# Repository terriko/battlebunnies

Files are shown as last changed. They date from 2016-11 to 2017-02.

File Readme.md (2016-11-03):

# Battle bunnies!

This is a goofy little side project that involves making a little electronic
bunny game in the name of learning a bit more about electronic badge design.

## How the game is played

Battle bunnies is meant to be a simple electronic game.  Each participant
gets their own bunny.  The bunnies have IR on one side of the PCB.
Participants line up their IR with the IR of another bunny and both hit the
"fight" button.  The bunnies each "roll" a random number 1-6 which is shown
on one ear and transmit that number to the other bunny.  The bunny with the
highest number gains a level.  In the case of a tie, both bunnies gain a
level (because why not?).  The levels are updated on the other ear.
Depending on how slow we want the level process to be, losing bunnies might
lose a level.

The "magic" button is an easter egg that can be activated when bunnies reach
max level.

## Bunny design

These are all early drafts which I'm sure we'll change.

### PCB outline
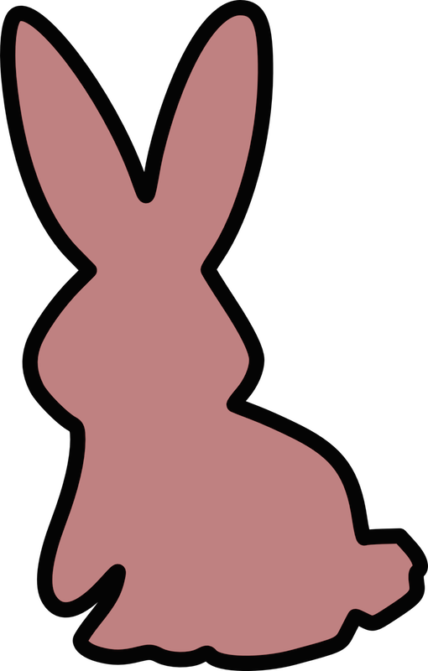
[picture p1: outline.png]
Battle Bunny PCB Outline


### Silkscreen bunny
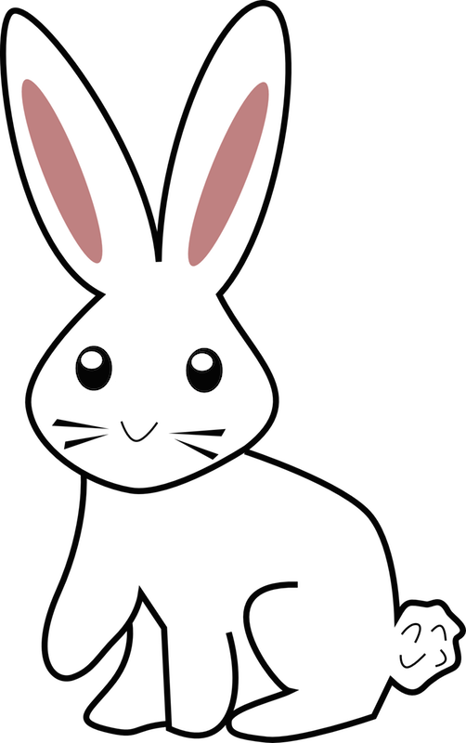
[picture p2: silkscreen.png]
Battle Bunny Silkscreen


### Explanation of what components go where
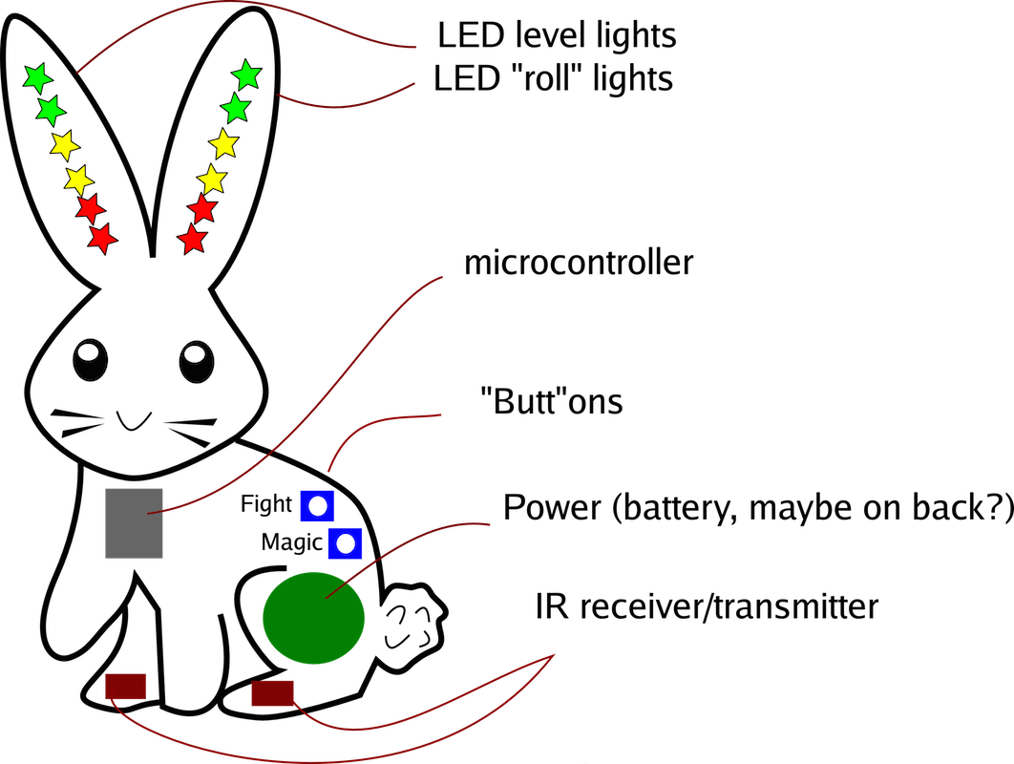
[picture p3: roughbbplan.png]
Battle Bunny details


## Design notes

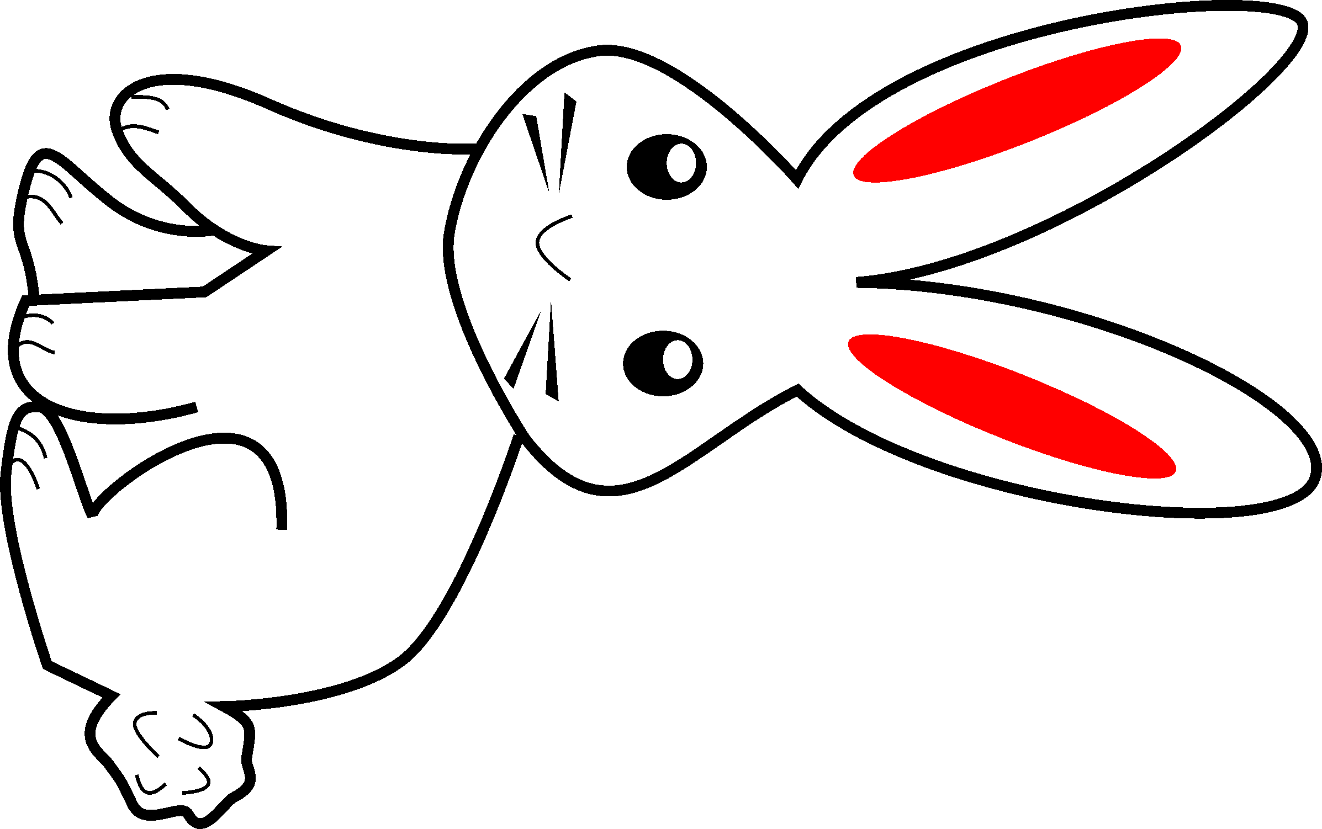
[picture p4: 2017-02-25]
battle bunnies silk.bmp

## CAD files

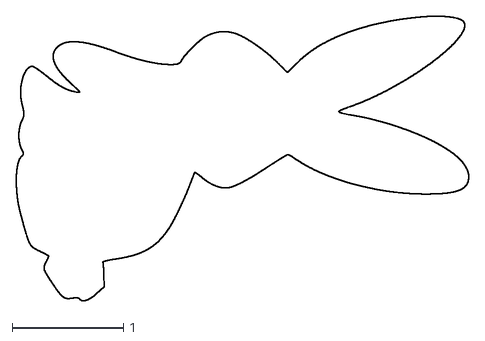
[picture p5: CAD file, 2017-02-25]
battlebunnies outline r9.dxf
4.07 x 2.56

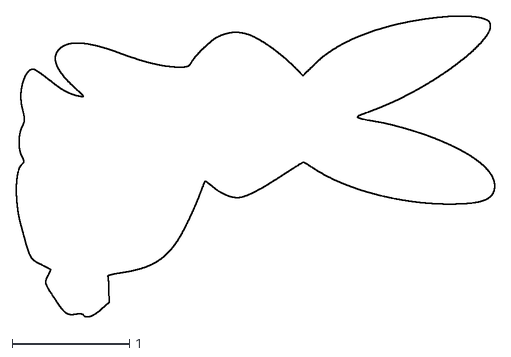
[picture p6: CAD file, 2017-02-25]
battlebunnies outline r12.dxf
4.07 x 2.56

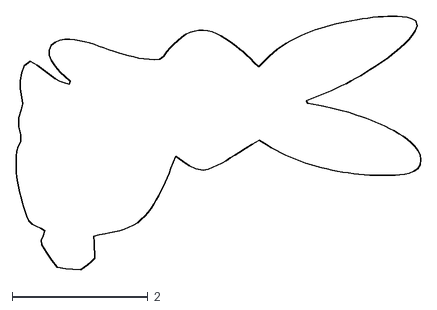
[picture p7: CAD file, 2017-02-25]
battlebunnies outline.dxf
5.97 x 3.74

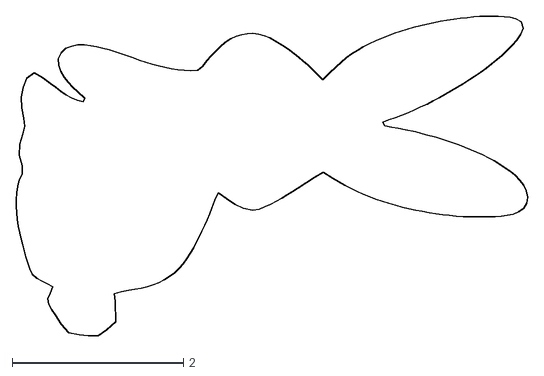
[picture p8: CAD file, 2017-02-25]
battlebunnies outline r12 v2.dxf
5.97 x 3.74

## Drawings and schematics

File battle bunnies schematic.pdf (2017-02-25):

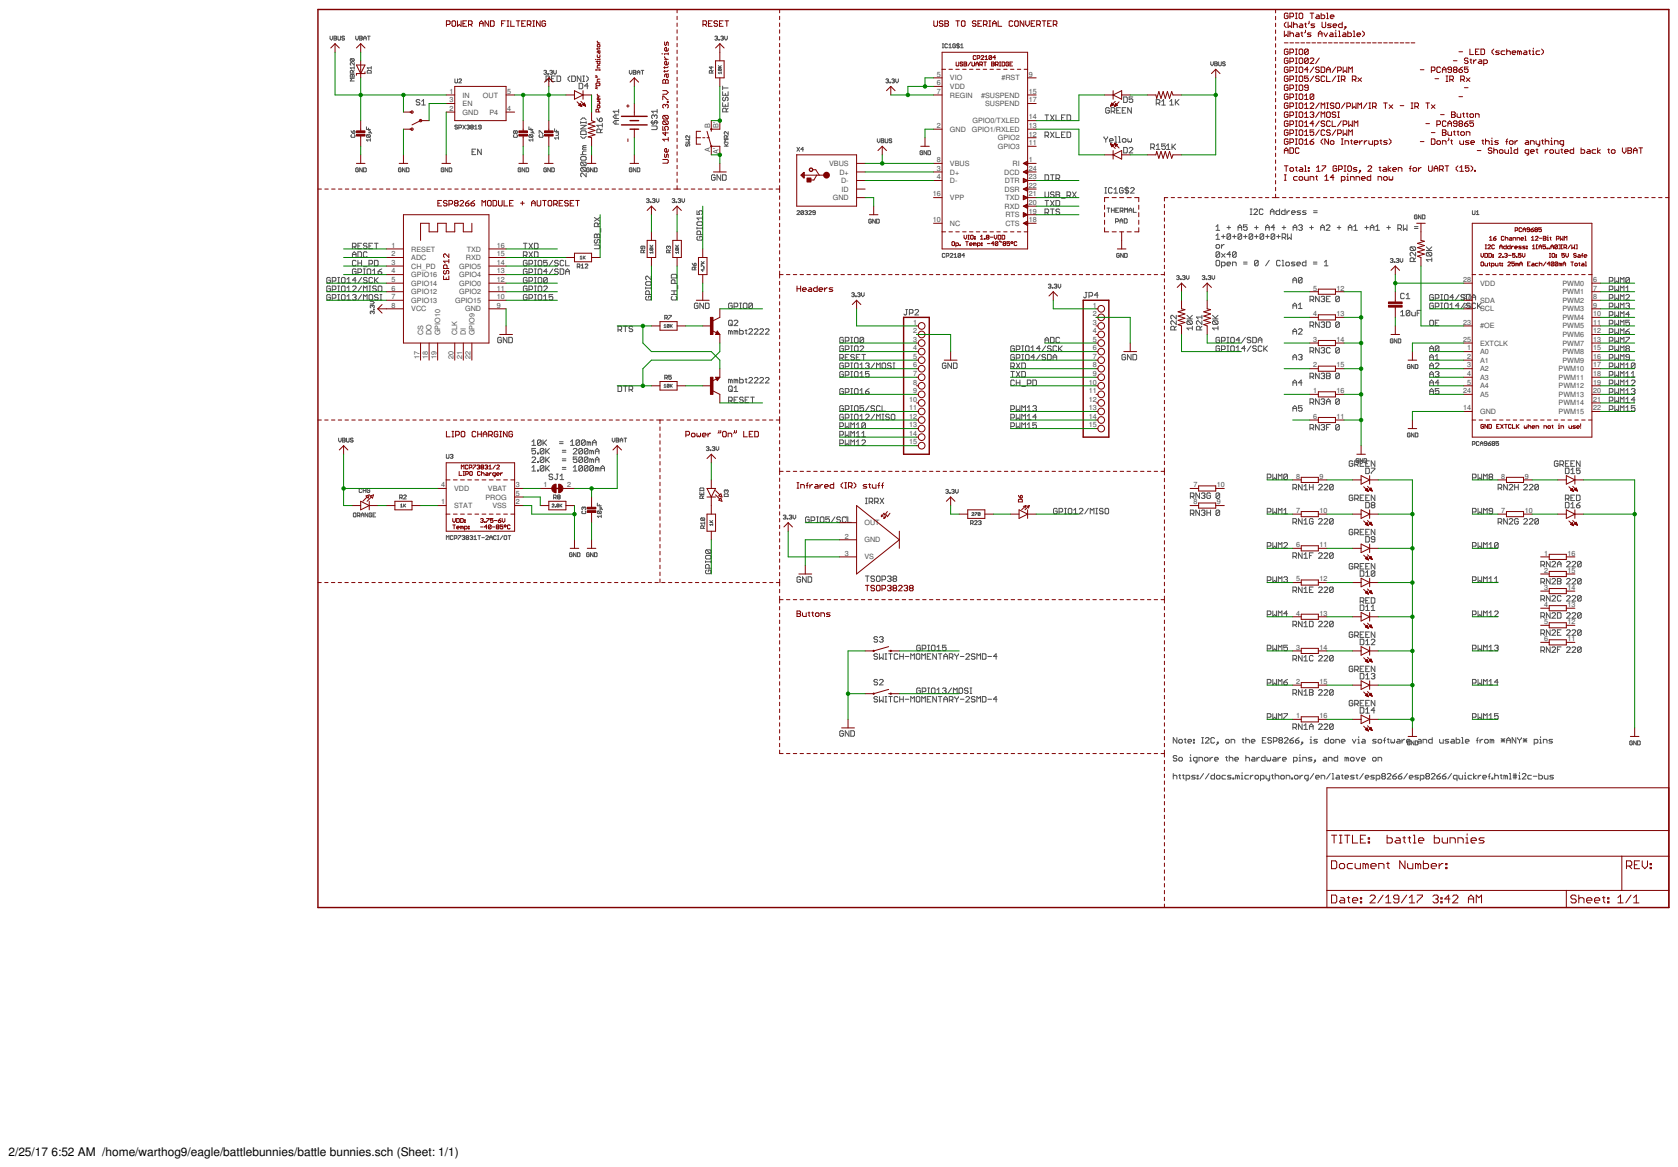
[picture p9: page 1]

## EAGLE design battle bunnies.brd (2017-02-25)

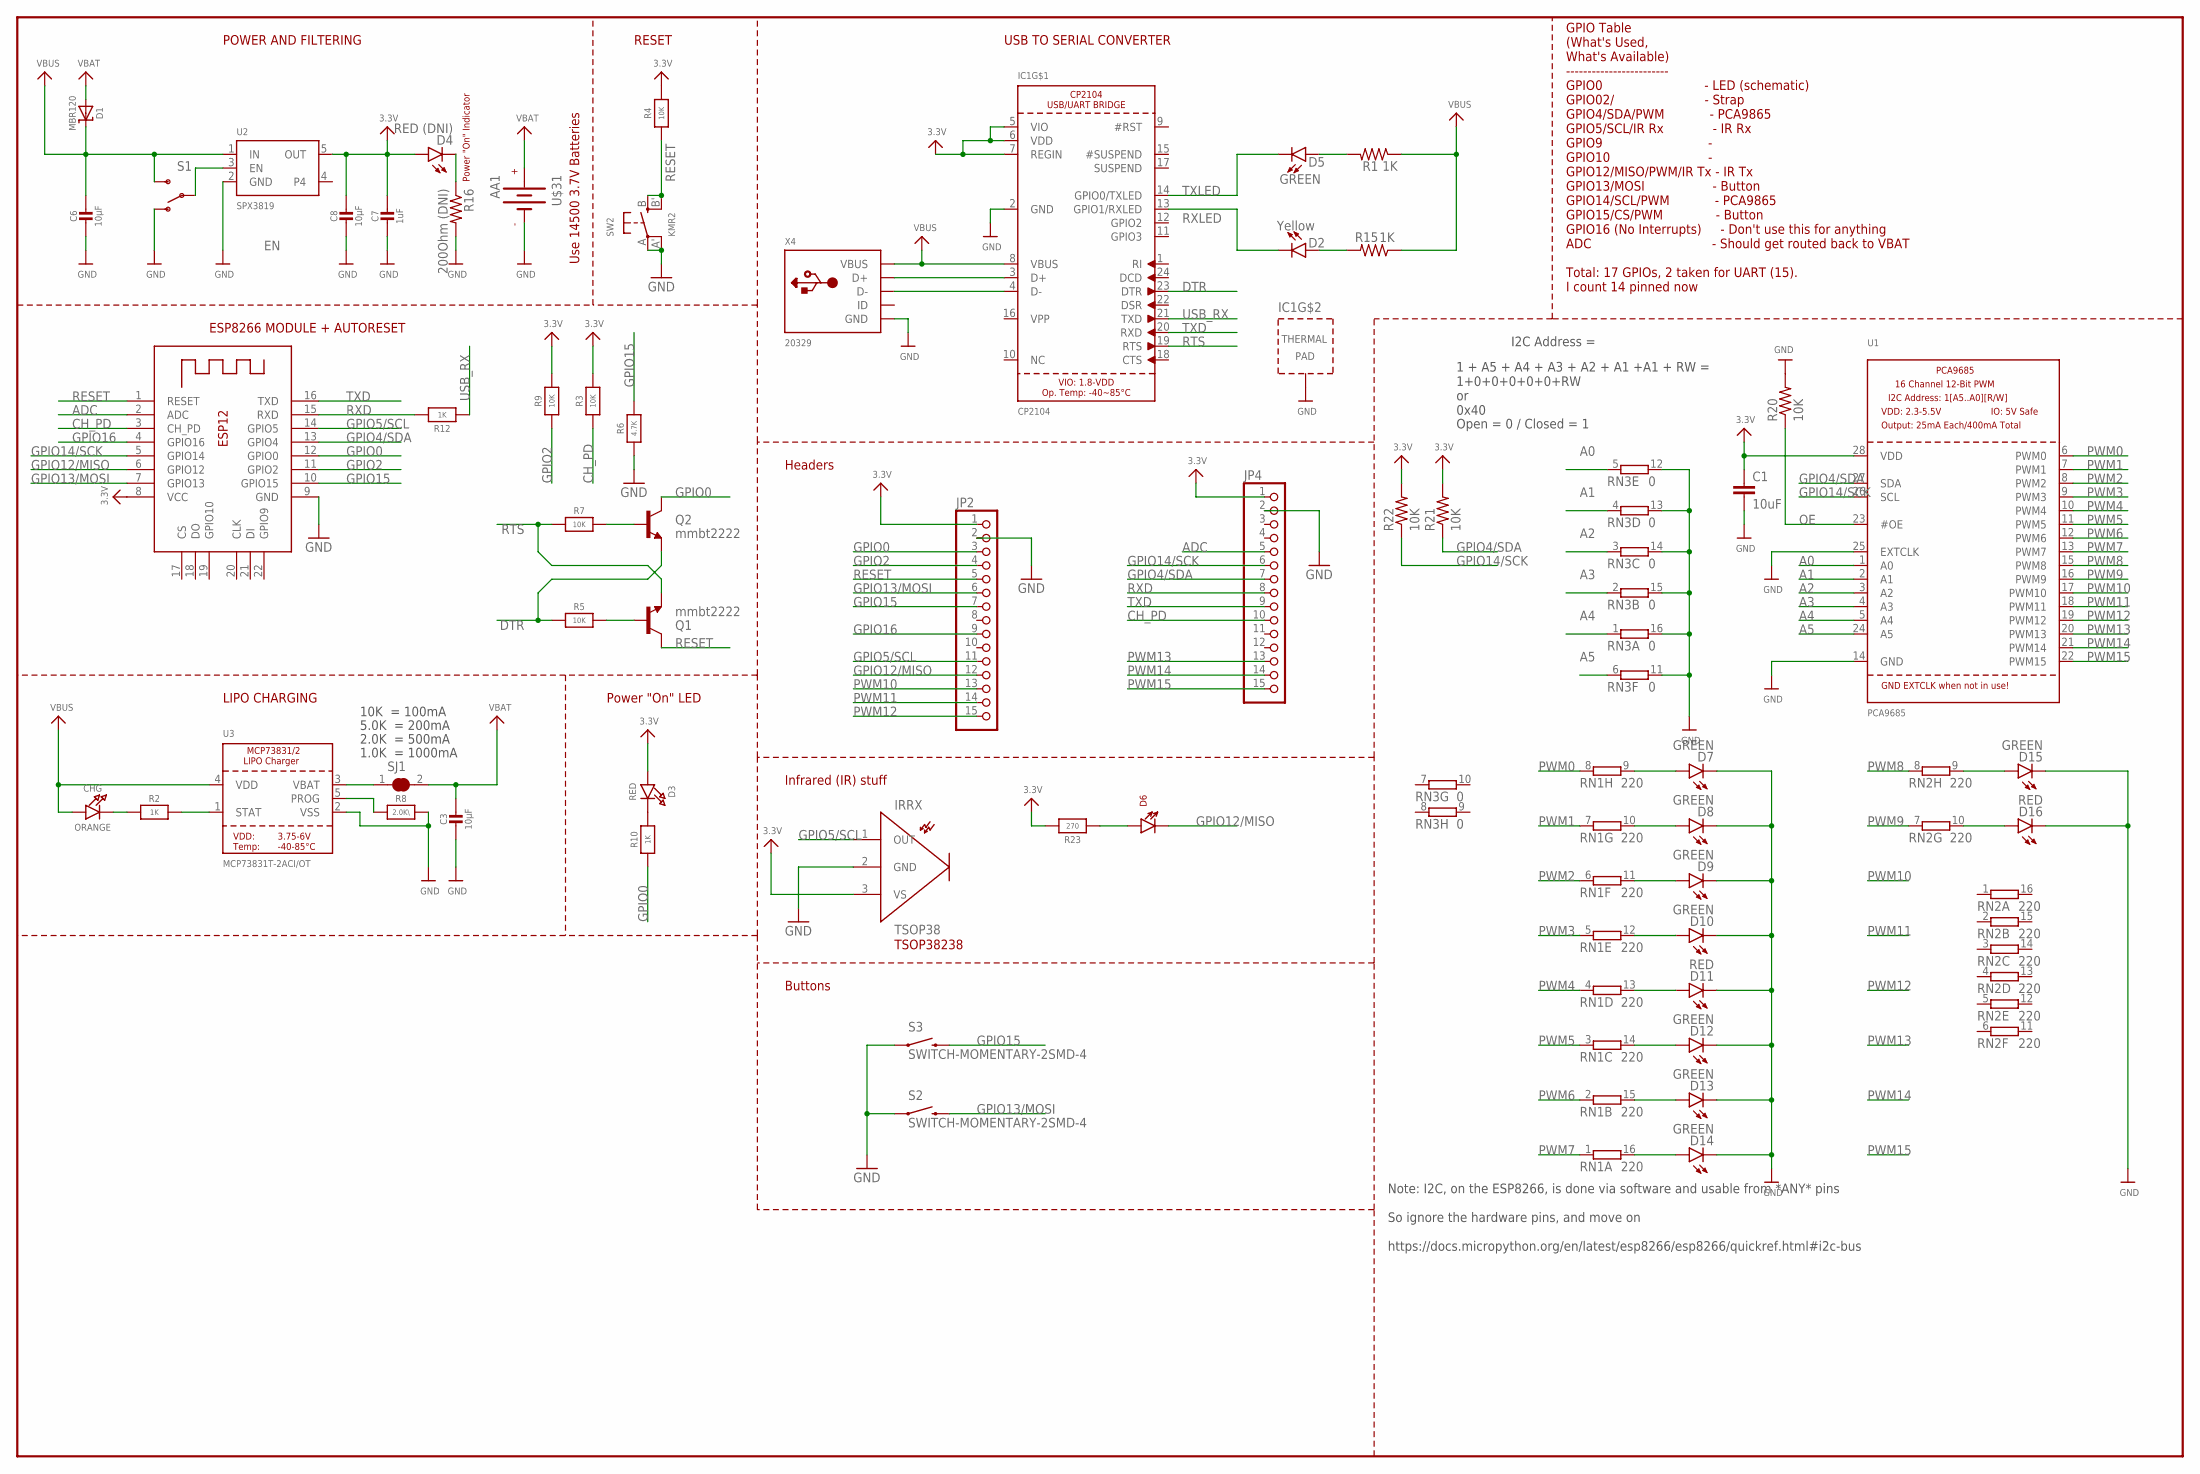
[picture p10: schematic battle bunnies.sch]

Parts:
C1: 10uF; 0805-CAP
C3, C6, C8: 10µF; 0805-NO
C7: 1uF; 0603-NO
CHG: ORANGE; CHIPLED_0805_NOOUTLINE
D1: MBR120; SOD-123
D2: Yellow; LED-0603
D3: RED; CHIPLED_0805_NOOUTLINE
D4: RED (DNI); LED-0603
D5, D7, D8, D9, D10, D12, D13, D14, D15: GREEN; LED-0603
D6: LTE-302
D11, D16: RED; LED-0603
IC1: CP2104; QFN24_4MM_SMSC
IRRX: TSOP38
JP2, JP4: PINHD-1X15; 1X15
Q1, Q2: mmbt2222; SOT23-3
R1, R15: 1K; 0603-RES
R2, R10: 1K; 0603-NO
R3, R4, R5, R9: 10K; 0603-NO
R6: 4.7K; 0603-NO
R7: 10K; _0603MP
R8: 2.0K\; 0603-NO
R12: 1K; _0603MP
R16: 200Ohm (DNI); 0603-RES
R20, R21, R22: 10K; 0805
R23: 270; 0603-NO
RN1, RN2: 220; EXB2HV
RN3: 0; EXB2HV
S1: SWITCH-SPDT-SMD-A; SWITCH-SPST-SMD-A
S2, S3: SWITCH-MOMENTARY-2SMD-4; TACTILE_SWITCH_TALL
SJ1: SOLDERJUMPER_CLOSED; SOLDERJUMPER_CLOSEDWIRE@1
SW2: KMR2; BTN_KMR2_4.6X2.8
U1: PCA9685; TSSOP28
U2: SPX3819; SOT23-5
U3: MCP73831T-2ACI/OT; SOT23-5
U$31: AA1
X2: ESP-12; ESP-12E
X4: 20329; 4UCONN_20329_V2

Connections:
3.3V: C1.1, C7.1, C8.1, D3.A, D4.A, IC1.5 (VIO), IC1.6 (VDD), IC1.7 (REGIN), IRRX.3 (VS), JP2.1, JP4.1, R1.1, R3.2, R4.2, R9.2, R15.1, R21.2, R22.2, R23.2, U1.28 (VDD), U2.5 (OUT), X2.8 (VCC)
A0: RN3.5 (1), U1.1 (A0)
A1: RN3.4 (1), U1.2 (A1)
A2: RN3.3 (1), U1.3 (A2)
A3: RN3.2 (1), U1.4 (A3)
A4: RN3.1, U1.5 (A4)
A5: RN3.6 (1), U1.24 (A5)
ADC: JP4.5, X2.2 (ADC)
CH_PD: JP4.10, R3.1, X2.3 (CH_PD)
DTR: IC1.23 (DTR), Q2.2 (E), R5.1
EN: S1.2, U2.3 (EN)
GND: C1.2, C3.2, C6.2, C7.2, C8.2, D7.C, D8.C, D9.C, D10.C, D11.C, D12.C, D13.C, D14.C, D15.C, D16.C, IC1.2 (GND), IC1.THERM (TP), IRRX.2 (GND), JP2.2, JP4.2, R6.1, R8.2, R16.2, R20.2, RN3.11 (2), RN3.12 (2), RN3.13 (2), RN3.14 (2), RN3.15 (2), RN3.16 (2), S1.1 (O), S2.A2 (1), S3.A2 (1), SW2.A, SW2.A' (P1), U1.14 (GND), U1.25 (EXTCLK), U2.2 (GND), U3.2 (VSS), U$31.NEG (-), X2.9 (GND), X4.BASE@1 (GND), X4.BASE@2 (GND), X4.GND, X4.SPRT@1 (GND), X4.SPRT@2 (GND), X4.SPRT@3 (GND), X4.SPRT@4 (GND)
GPIO0: JP2.3, Q2.3 (C), R10.1, X2.12 (GPIO0)
GPIO2: JP2.4, R9.1, X2.11 (GPIO2)
GPIO4/SDA: JP4.7, R21.1, U1.27 (SDA), X2.13 (GPIO4)
GPIO5/SCL: IRRX.1 (OUT), JP2.11, X2.14 (GPIO5)
GPIO12/MISO: D6.C, JP2.12, X2.6 (GPIO12)
GPIO13/MOSI: JP2.6, S2.B2 (2), X2.7 (GPIO13)
GPIO14/SCK: JP4.6, R22.1, U1.26 (SCL), X2.5 (GPIO14)
GPIO15: JP2.7, R6.2, S3.B2 (2), X2.10 (GPIO15)
GPIO16: JP2.9, X2.4 (GPIO16)
unnamed: CHG.C, R2.1
unnamed: R8.1, U3.5 (PROG)
unnamed: R2.2, U3.1 (STAT)
unnamed: D4.C, R16.1
unnamed: D3.C, R10.2
unnamed: D5.A, R1.2
unnamed: SJ1.1, U3.3 (VBAT)
unnamed: D2.A, R15.2
unnamed: Q1.1 (B), R5.2
unnamed: Q2.1 (B), R7.2
unnamed: D6.A, R23.1
unnamed: D13.A, RN1.15 (2)
unnamed: D14.A, RN1.16 (2)
unnamed: D12.A, RN1.14 (2)
unnamed: D11.A, RN1.13 (2)
unnamed: D10.A, RN1.12 (2)
unnamed: D9.A, RN1.11 (2)
unnamed: D8.A, RN1.10 (2)
unnamed: D7.A, RN1.9 (2)
unnamed: D15.A, RN2.9 (2)
unnamed: D16.A, RN2.10 (2)
OE: R20.1, U1.23 (#OE)
PWM0: RN1.8 (1), U1.6 (PWM0)
PWM1: RN1.7 (1), U1.7 (PWM1)
PWM2: RN1.6 (1), U1.8 (PWM2)
PWM3: RN1.5 (1), U1.9 (PWM3)
PWM4: RN1.4 (1), U1.10 (PWM4)
PWM5: RN1.3 (1), U1.11 (PWM5)
PWM6: RN1.2 (1), U1.12 (PWM6)
PWM7: RN1.1, U1.13 (PWM7)
PWM8: RN2.8 (1), U1.15 (PWM8)
PWM9: RN2.7 (1), U1.16 (PWM9)
PWM10: JP2.13, U1.17 (PWM10)
PWM11: JP2.14, U1.18 (PWM11)
PWM12: JP2.15, U1.19 (PWM12)
PWM13: JP4.13, U1.20 (PWM13)
PWM14: JP4.14, U1.21 (PWM14)
PWM15: JP4.15, U1.22 (PWM15)
RESET: JP2.5, Q1.3 (C), R4.1, SW2.B (S), SW2.B' (S1), X2.1 (RESET)
RTS: IC1.19 (RTS), Q1.2 (E), R7.1
RXD: JP4.8, R12.2, X2.15 (RXD)
RXLED: D2.C, IC1.13 (GPIO1/RXLED)
TXD: IC1.20 (RXD), JP4.9, X2.16 (TXD)
TXLED: D5.C, IC1.14 (GPIO0/TXLED)
USBD_N: IC1.4 (D-), X4.D-
USBD_P: IC1.3 (D+), X4.D+
USB_RX: IC1.21 (TXD), R12.1
VBAT: C3.1, D1.A, SJ1.2, U$31.POS (+)
VBUS: C6.1, CHG.A, D1.C, IC1.8 (VBUS), S1.3 (S), U2.1 (IN), U3.4 (VDD), X4.VBUS

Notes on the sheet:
POWER AND FILTERING
RESET
10K = 100mA
5.0K = 200mA
2.0K = 500mA
1.0K = 1000mA
USB TO SERIAL CONVERTER
LIPO CHARGING
Power "On" LED
ESP8266 MODULE + AUTORESET
Power "On" Indicator
GPIO Table (What's Used, What's Available) ------------------------ GPIO0 - LED (schematic) GPIO02/ - Strap GPIO4/SDA/PWM - PCA9865 GPIO5/SCL/IR Rx - IR Rx GPIO9 - GPIO10 - GPIO12/MISO/PWM/IR Tx - IR Tx GPIO13/MOSI - Button GPIO14/SCL/PWM - PCA9865 GPIO15/CS/PWM - Button GPIO16 (No Interrupts) - Do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
1 + A5 + A4 + A3 + A2 + A1 +A1 + RW = 1+0+0+0+0+0+RW or 0x40
I2C Address =
Open = 0 / Closed = 1
Note: I2C, on the ESP8266, is done via software and usable from *ANY* pins So ignore the hardware pins, and move on https://docs.micropython.org/en/latest/esp8266/esp8266/quickref.html#i2c-bus
Headers
Infrared (IR) stuff
TSOP38238
Buttons
Use 14500 3.7V Batteries

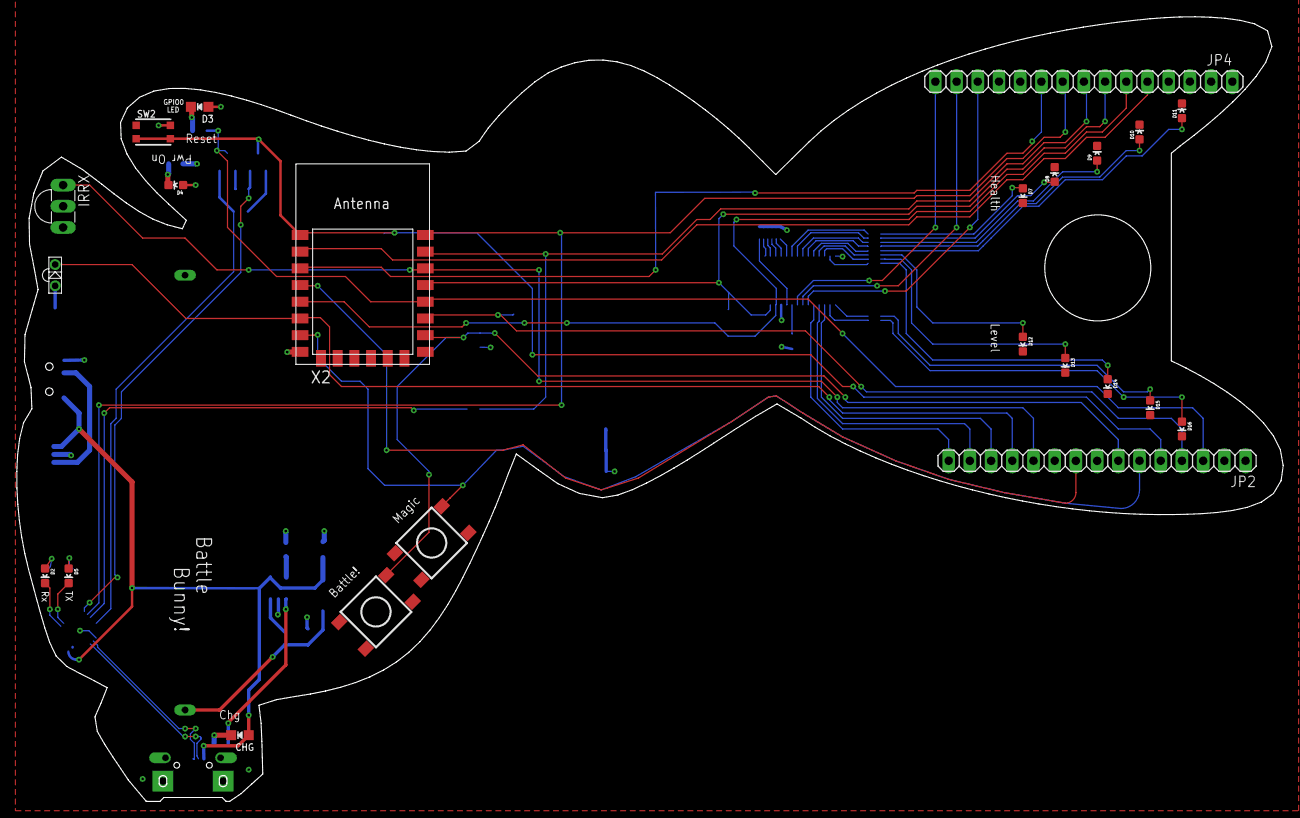
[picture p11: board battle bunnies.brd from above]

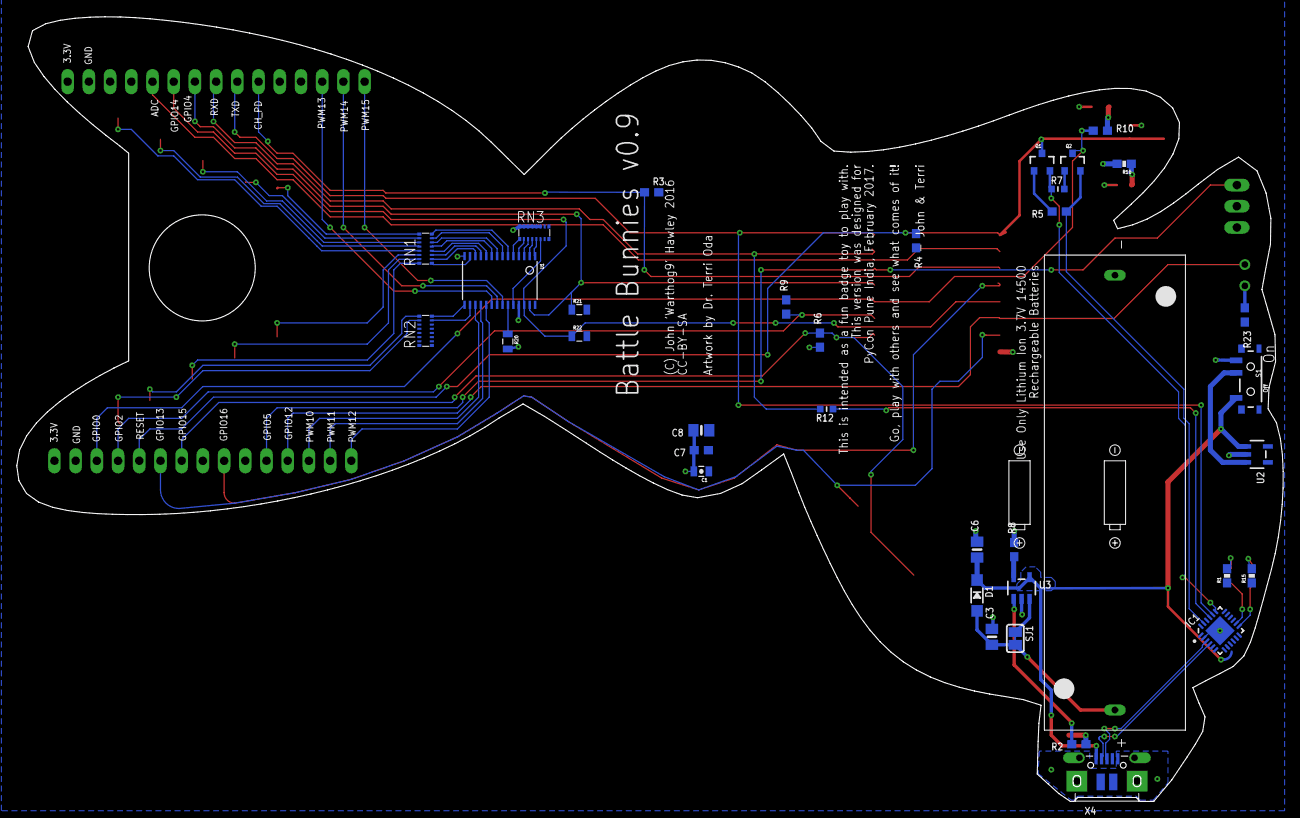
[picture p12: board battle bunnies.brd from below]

Board: 2 copper layers, 151.7 x 94.0 mm, 59 parts (36 on the bottom side), 70 nets.

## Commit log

2017-01-02 Adding Board Schematic, Layout, & additional files for design
    [battle bunnies.brd, battle bunnies.sch, battlebunnies outline r12 v2.dxf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]
2017-01-25 Fixing Power LED
    Right now the 'Power LED' is run from Ground to... Ground, so it's
    not exactly going to work 'right'. When moving things around in
    Eagle it didn't attach properly to the 3.3V line on the schematic
    and so was left dangling, despite it being connected.
    This, thankfully, doesn't affect the boards except cause a little
    bit of build waste. This is fixed now, though it'll likely get
    set to DNI, as it's only really useful on dev boards.
    [battle bunnies.brd, battle bunnies.sch]
2017-01-25 Updating GPIO Table to actually be correct with the schematic
    [battle bunnies.sch]
2017-01-25 Flipping GPIO16 with GPIO15 on the 'Battle' Button
    GPIO16 *APPARENTLY* doesn't actually have hard interrupt
    support, which makes it slightly obnoxious for the 'battle'
    button, which should be there to wake the bunny from a sleep
    state, or get it to do something.
    [battle bunnies.brd, battle bunnies.sch]
2017-01-25 Marking the "Power On" LEDs as DNI
    They aren't needed and adding them is more a debugging
    nicety vs. a critical need.
    [battle bunnies.brd, battle bunnies.sch]
2017-01-25 Marking On/Off on the main power switch
    [battle bunnies.brd]
2017-02-25 Adding warning / notice about battery to be used
    [battle bunnies.brd]
2017-02-25 Fixing the trace that ran through the exposed ear
    [battle bunnies.brd]
2017-02-25 Updating the GPIO table
    Turns out 16 is really unusable for anything even
    remotely useful. (case in point it has no pull-up available)
    [battle bunnies.sch]
2017-02-25 Removing extraneous via on GPIO14/SCK
    [battle bunnies.brd]
2017-02-25 Fixing the USB impedance issue (moving USB chip)
    This is a pretty big change as I'm moving a bunch of stuff around
    which obviously causes it's own issues, but this should be ok
    [battle bunnies.brd]
2017-02-25 Adding some clearances around lines passing through the ESP8266
    This *SHOULDN'T* be the problem with the IR RX but it can't hurt
    [battle bunnies.brd]
2017-02-25 Cleaning up various DRC errors (mostly stop mask issues)
    This should also make the general text easier to read
    [battle bunnies.brd]
2017-02-25 Adding values to the RNs that were missing
    [battle bunnies.brd, battle bunnies.sch]
2017-02-25 Adding back in the lanyard hole
    Oops
    [battle bunnies.brd]
2017-02-25 Smashing RN3 to deal with DRC errors
    [battle bunnies.brd]
2017-02-25 Adding a PDF version of the schematic
    I don't garauntee it to be up to date with the actual schematic
    so take it with a grain of salt

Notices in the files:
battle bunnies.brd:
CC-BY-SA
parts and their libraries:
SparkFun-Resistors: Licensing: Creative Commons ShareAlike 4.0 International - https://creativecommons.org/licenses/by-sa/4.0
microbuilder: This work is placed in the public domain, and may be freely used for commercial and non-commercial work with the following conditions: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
